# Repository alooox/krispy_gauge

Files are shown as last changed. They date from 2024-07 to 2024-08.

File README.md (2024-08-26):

# Krispy Gauge
A Open Source Digital Circular Customisable Touchscreen Canbus Gauge



This gauge is currently being optimised for Haltech ECU's https://www.haltech.com but could easily be modified for other ECU's by editing the canbus.ino Values

**Parts Only Kits Available Soon** and will be available at https://shop.krispy.co.nz

**Assembeled Gauges Available Soon** and will be available at https://shop.krispy.co.nz

## Functions

Live display of data from the Haltech Canbus (OpenCan)

1.28 Inch 240x240 Touchscreen Display

Wifi Control Panel

Haltech Keypad Emulation

Daisy Chain Support

Multiple Gauge Display Modes (Single, Dual, Quad) (And more coming soon)

Max and Min Value Warning Support

Check Engine light Display 

Firmware updatable via OTA (Wifi Updating)

## Use

Connect the gauge via the 4 Pin Connector to Switched Ignition 12v Power, Ground, CAN_H and CAN_L

When the ignition is on, the gauge will boot up and display its unique ID, version number, and supported ECU. 

You can then connect to the wifi hotspot with the password "getKrispy" or by tapping the settings icon, you can tap wifi to see the SSID and Password

Next the webpage 4.3.2.1 should open depending on your Phone/Laptop's captive portal settings, if it does not open, navigate to https://4.3.2.1

You are now accessing the Gauge configuration Page, set Colours, Refresh Rate, CEL, Wifi, Metrics, Max and Min Values as well as Keypad Emulation settings from this page. 



At the bottom of the page you will find information on reseting to factory defaults, rebooting the gauge, and upgrading its firmware to a new version, this all can be done from a Phone/Laptop/Tablet

## Hardware

### Essential Components : 

Seeed Studio XIAO CAN Bus Board (MCP2515) https://s.click.aliexpress.com/e/_Dl9nxDh

Seeed Studio XIAO 1.28 Inch Touch Round Display https://s.click.aliexpress.com/e/_DdEk9zZ

Seeed Studio XIAO ESP32 C3 Wifi/Bluetooth https://s.click.aliexpress.com/e/_DDLxWcL

12v to 5v DC Step Down https://www.aliexpress.com/item/1005001629723875.html (Ensure selecting 5V Model)

### Extra Hardware : 

7 Pin Male Header https://s.click.aliexpress.com/e/_DcYtd1t (Select 7P)  

4 Wire Flex Cable 20cm x 4 pins https://s.click.aliexpress.com/e/_DF3jjPN (Select Same Side, 20CM, 4P) 

4 Pin PCB Header https://www.aliexpress.com/item/4000029705975.html 

6 Pin Right Angle Pins https://s.click.aliexpress.com/e/_Dkx5ZRH (Select 2x6 Pin) 

Single Right Angle Pins https://s.click.aliexpress.com/e/_DEGFR75 (Any Selection)

M2 x 6mm Stainless Button Screws https://s.click.aliexpress.com/e/_DFWEuzl (Select M2 x 6mm)

SuperGlue/CA Glue for front Bezel Adhesion 

### 3D Printed Files :
https://github.com/alooox/krispy_gauge/blob/main/STL

3D Print with JLC3DP https://jlc3dp.com/?from=alexproctor

Print one of each of the following parts

1x Main Housing (Recomended 0.15mm to 0.2 Layer height, and Buildplate only supports)

1x Front Bezel (Smallest Layer Height Recomended, 0.10mm or below)

1x Bezel Assembily Tool (0.2mm Layer height)

1x Clamp (0.15mm Layer height)

1x End Cap (0.2mm Layer height)

1x Internal Spacer (0.2mm Layer height)

1x Clamp Tool (0.2mm Layer height) 

### PCB Files : 
https://github.com/alooox/krispy_gauge/tree/main/PCB

Technically the gauge could be assembeled without these custom PCB's but it involves soldering several tiny wires between the 3 boards, the PCB itself actus as a structual part of the gauge, linking all the components together and firmly afixing them to the 3D Pritned housing. 

1x Display to Canbus PCB 

1x ECU to Gauge Backplane PCB

I recomend JLCPCB or PCBWay to get these PCB's Produced

PCB from JLCPCB https://jlcpcb.com/?from=alexproctor1

## Software

Precompiled Builds for the Krispy Gauge are available here (LINK)

If you wish to compile Krispy Gauge yourself you will require the following Libraries 

MCP CAN : https://github.com/coryjfowler/MCP_CAN_lib

TFT_eSPI : https://github.com/Bodmer/TFT_eSPI

SEEED Round Display : https://github.com/Seeed-Studio/Seeed_Arduino_RoundDisplay

LVGL : https://github.com/lvgl/lvgl

File Additions
1. Setup66_Seeed_XIAO_Round.h will need to be copied to Documents\Arduino\libraries\TFT_espi\User_Setups
2. User_Setup_Select.h will need to be copied to Documents\Arduino\libraries\TFT_eSPI\

## Thanks and Mentions

A Special thanks to https://github.com/tolunaygul and https://github.com/analoghan for some of the Keypad Emulation Code
And Special thanks to Haltech for making such awesome products

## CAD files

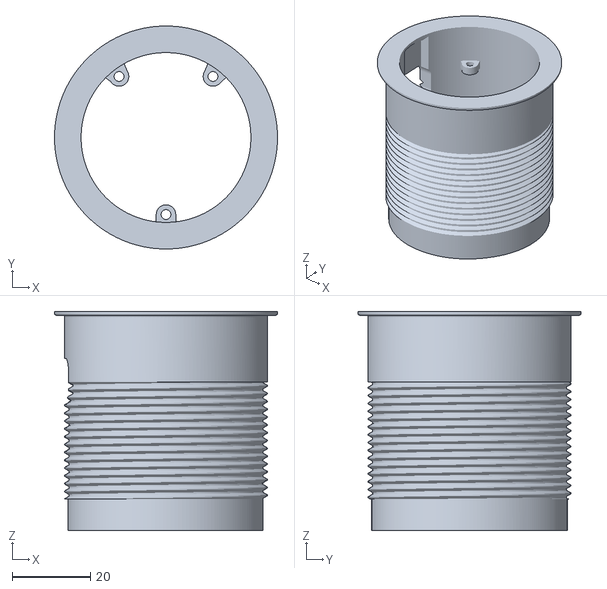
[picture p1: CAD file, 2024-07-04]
STL/Main_Housing.stl
57.0 x 57.0 x 56.0

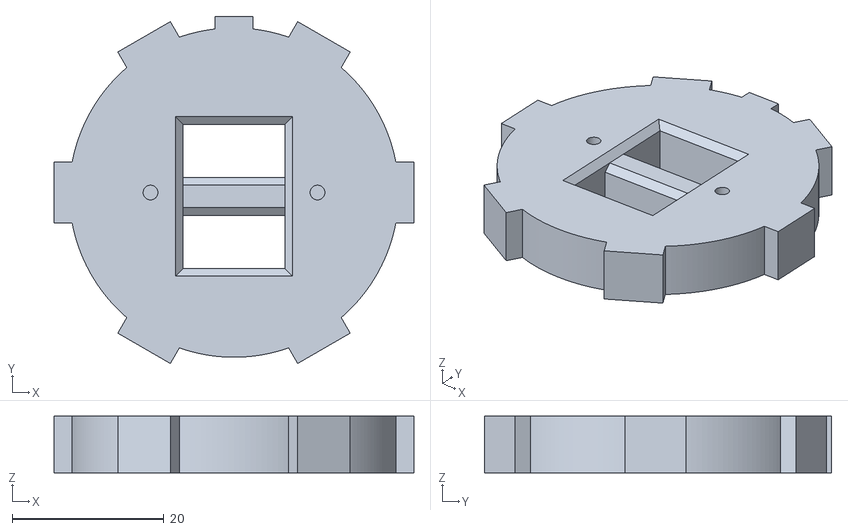
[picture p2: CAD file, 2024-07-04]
STL/End_Cap.stl
47.4 x 45.7 x 7.50

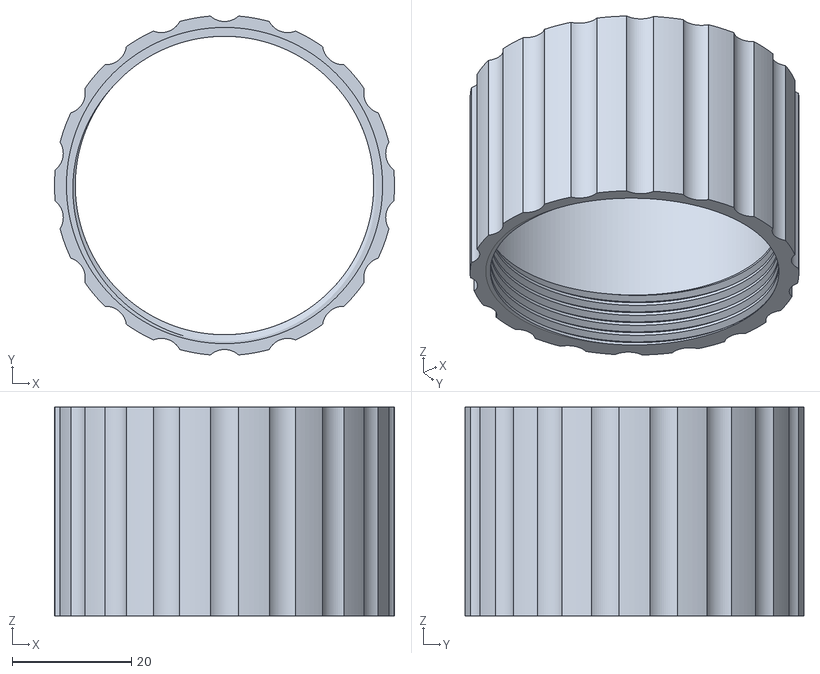
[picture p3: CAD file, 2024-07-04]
STL/Clamp.stl
57.0 x 56.8 x 35.0

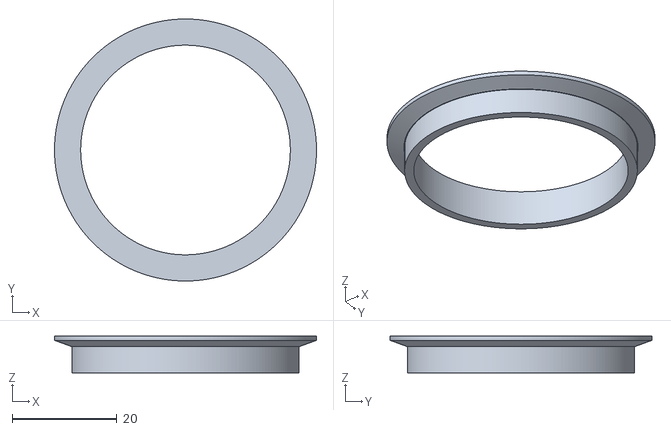
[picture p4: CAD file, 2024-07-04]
STL/Bezel_Assembily_Tool.stl
50.0 x 50.0 x 7.00

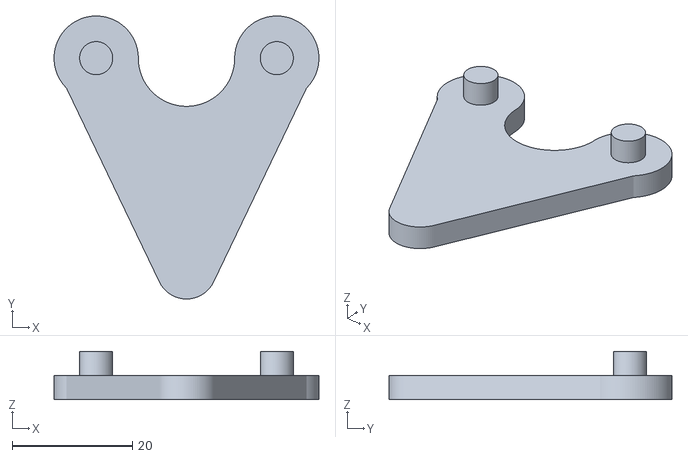
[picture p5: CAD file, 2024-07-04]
STL/Clamp_Tool.stl
44.0 x 47.0 x 8.00

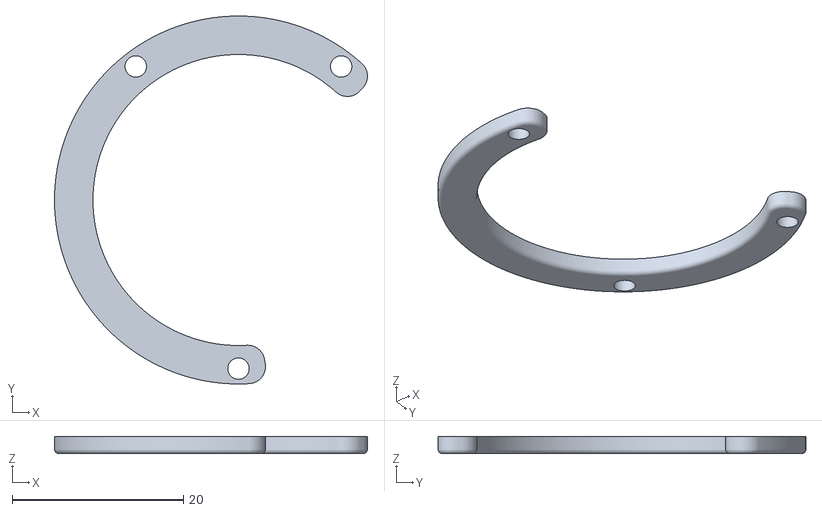
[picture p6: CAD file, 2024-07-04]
STL/Spacer.stl
36.6 x 43.0 x 2.00

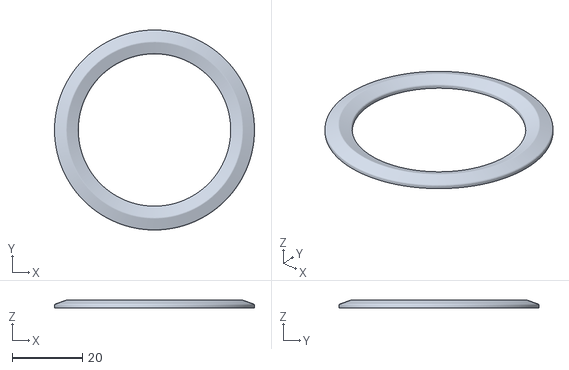
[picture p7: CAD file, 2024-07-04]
STL/Front_Bezel.stl
57.0 x 57.0 x 2.21

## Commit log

2024-07-04 Uploaded STL and OBJ Files for Gauge Housing
    [Bezel_Assembily_Tool.stl, Clamp.stl, Clamp_Tool.stl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]
2024-07-04 Uploading PCB Gerber and EASYEDA Files
